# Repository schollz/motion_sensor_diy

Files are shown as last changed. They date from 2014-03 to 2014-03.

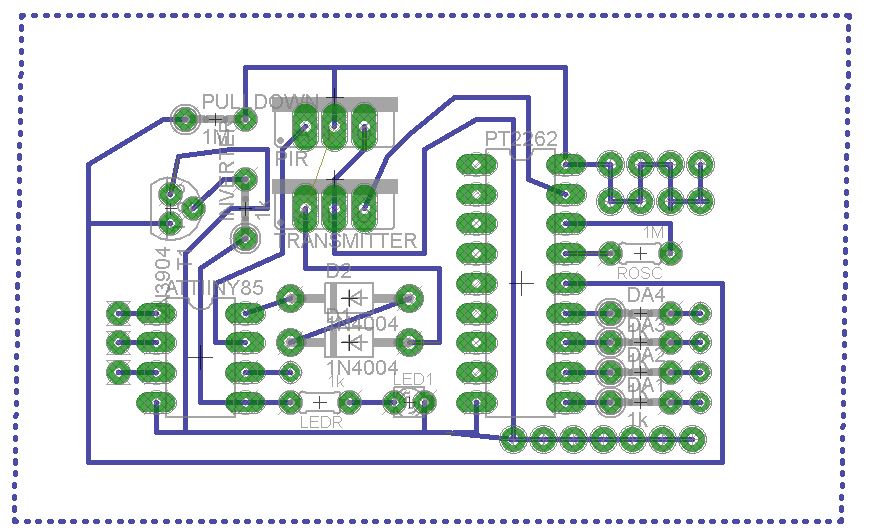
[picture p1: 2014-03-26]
eagle/rf_tx_board.JPG

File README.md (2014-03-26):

motion_sensor_diy
=================

Electronic schematics for RF motion sensor that uses Arduino as receiver hub

Instructions
=================

The eagle schematics show the wiring for the Motion Sensor and the Receiver. Each is very simple, here is the run down:

<h1>Motion sensor + RF transmitter</h1>

<strong>Components</strong>
<ul>
<li><a href="https://www.google.com/url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,d.cWc">PIR sensor</a>, on <a href="http://www.amazon.com/HC-SR501-Sensor-Module-Pyroelectric-Infrared/dp/B007XQRKD4">Amazon</a> or <a href="http://www.ebay.com/itm/10pcs-HC-SR501-Adjust-IR-Pyroelectric-Infrared-PIR-Motion-Sensor-Detector-Module-/131028677440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">Ebay</a></li>
<li><a href="http://www.100y.com.tw/pdf_file/PT2262-IRS.PDF">PT2262 encoder</a></li>
<li><a href="http://www.atmel.com/images/atmel-2586-avr-8-bit-microcontroller-attiny25-attiny45-attiny85_datasheet.pdf">ATtiny85</a></li>
<li><a href="http://www.amazon.com/433Mhz-transmitter-receiver-your-Experiment/dp/B00AMB3NCY">434 MHz RF transmitter</a></li>
<li>Several 500-1k Ohm resistors</li>
<li>LED (optional)</li>
</ul>

The motion sensor is simply a PIR sensor connected to a 434MHz RF transmitter via an encoder. The encoder uses four bits, in the form of resistors tied to HIGH (+VCC) or LOW (GND). That's enough for 12 sensors. 
The ATtiny85 is programmed via an Arduino which allows for devising a smart way of sending the RF data. It can be programmed to send the output as randomized timed sequences in order to reduce the conflicts of having other motion sensors on the same band.

<h1>RF Receiver</h1>

<strong>Components</strong>
<ul>
<li>Arduino</li>
<li>PT2272 encoder</li>
<li>434 MHz RF receiver</li>
</ul>

This circuit is even simpler. Connect the RF receiver output to the DIN of the PT2272. Then put each output pin (the four bits) into the Arduino pins 3-6. It's best to connect the VT (Viable Transmission indicator) pin of the PT2272 to the Pin 2 of the Arduino so that you can attach an interrupt on it. This way whenever VT goes high, the Arduino will read the other four pins and use that to determine which sensor is which (I leave this to you, though).

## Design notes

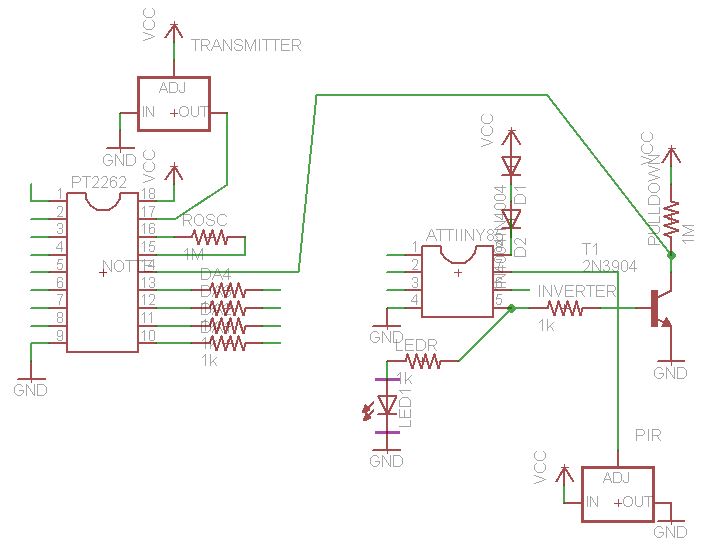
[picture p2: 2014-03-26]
eagle/rf_tx_schematic.JPG

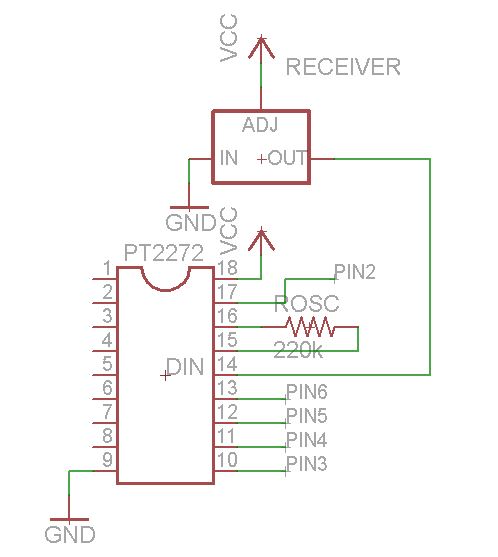
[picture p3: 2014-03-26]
eagle/rf_rx_schematic.JPG

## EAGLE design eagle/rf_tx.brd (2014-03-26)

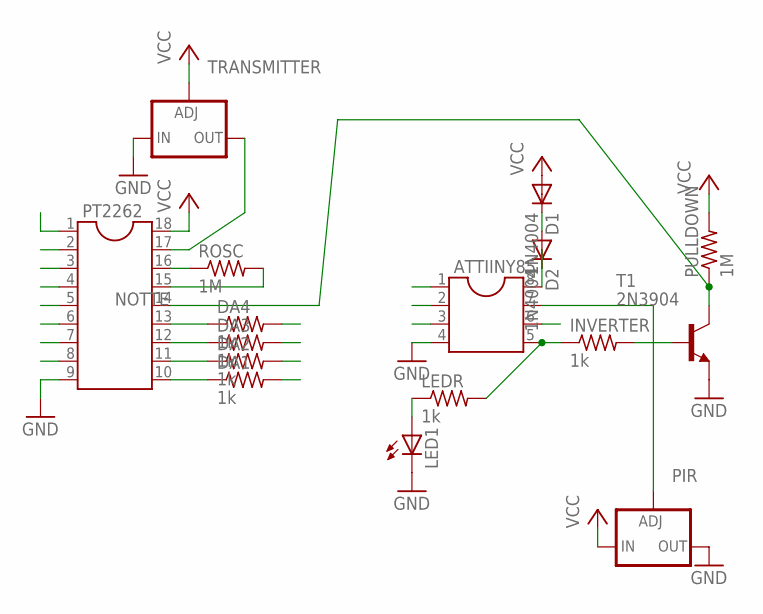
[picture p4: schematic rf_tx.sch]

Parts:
ATTIINY85: DIL8; DIL08
D1, D2: 1N4004; DO41-10
DA1, DA2, DA3, DA4: 1k; 0207/5V
INVERTER: 1k; 0207/5V
LED1: LED_ELD260; LED_LD260
LEDR: 1k; 0204/5
PIR: LM337TS; 337TS
PT2262: DIL18
PULLDOWN: 1M; 0207/5V
ROSC: 1M; 0204/5
T1: 2N3904; TO92
TRANSMITTER: LM337TS; 337TS

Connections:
GND: ATTIINY85.4, LED1.K (C), PIR.3 (OUT), PT2262.9, T1.3 (E), TRANSMITTER.2 (IN)
unnamed: D1.C, D2.A
unnamed: ATTIINY85.8, D2.C
unnamed: INVERTER.2, T1.2 (B)
unnamed: ATTIINY85.7, PIR.1 (ADJ)
unnamed: LED1.A, LEDR.1
unnamed: PT2262.17, TRANSMITTER.3 (OUT)
unnamed: PT2262.16, ROSC.1
unnamed: PT2262.15, ROSC.2
unnamed: DA1.1, PT2262.10
unnamed: DA3.1, PT2262.12
unnamed: DA2.1, PT2262.11
unnamed: DA4.1, PT2262.13
unnamed: ATTIINY85.5, INVERTER.1, LEDR.2
NOTTE: PT2262.14, PULLDOWN.1, T1.1 (C)
VCC: D1.A, PIR.2 (IN), PT2262.18, PULLDOWN.2, TRANSMITTER.1 (ADJ)

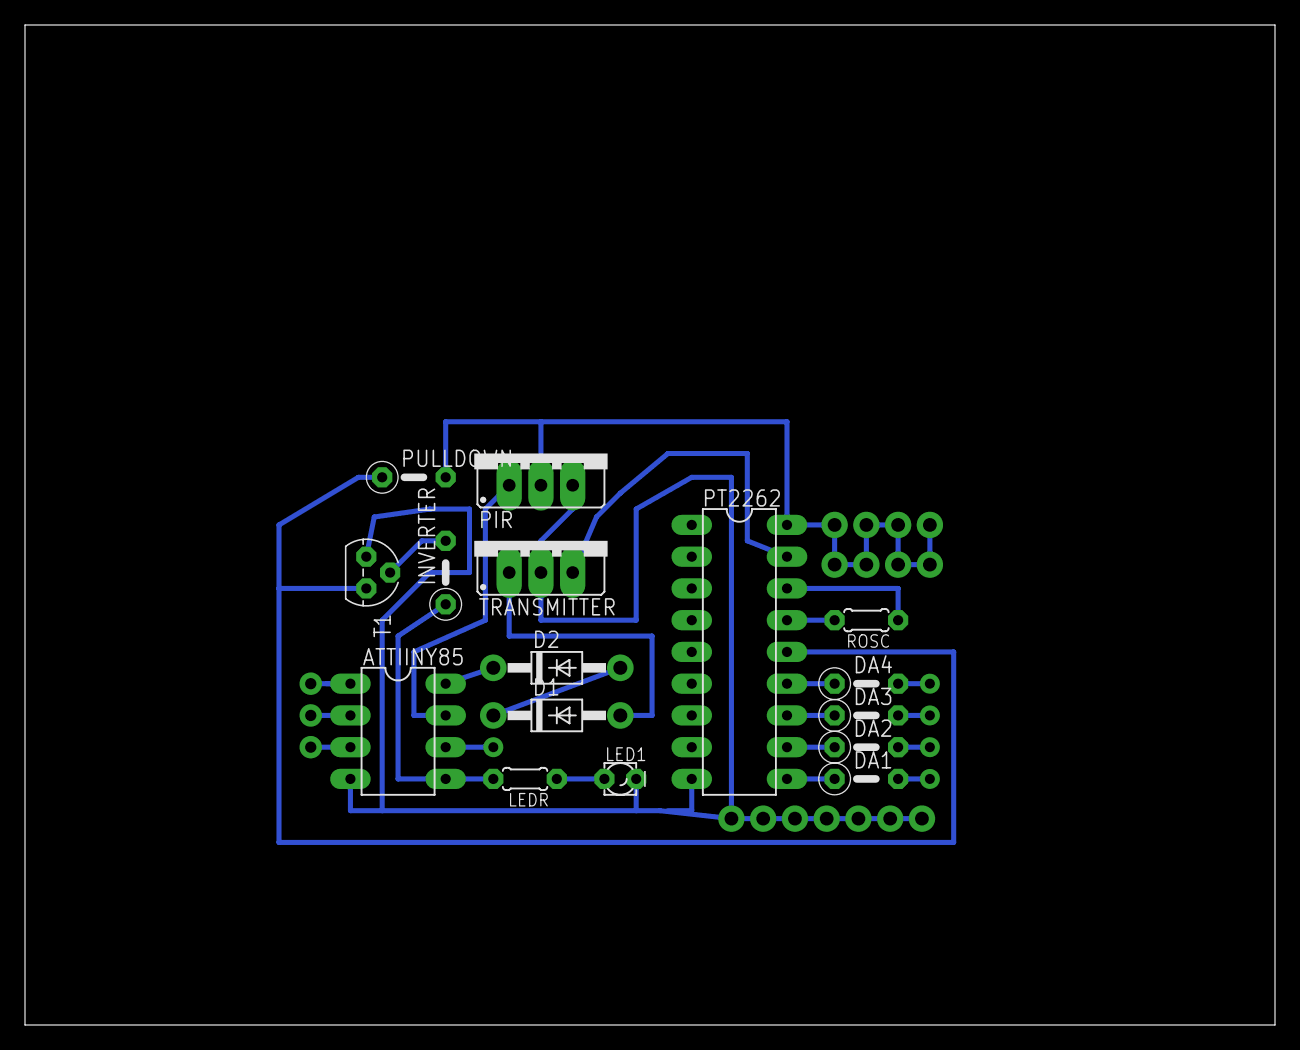
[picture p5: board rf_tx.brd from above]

Board: 2 copper layers, 100.0 x 80.0 mm, 16 parts (0 on the bottom side), 16 nets.

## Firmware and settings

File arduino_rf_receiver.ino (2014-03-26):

int ledpin = 13;
volatile int state = LOW;

void setup()
{
  pinMode(pin, OUTPUT);
  attachInterrupt(0, blink, CHANGE); //pin 2
  Serial.begin(9600);
}

void loop()
{
  digitalWrite(ledpin, state);
}

void blink()
{
  int a = digitalRead(3);
  int b = digitalRead(4);
  int c = digitalRead(5);
  int d = digitalRead(6);
  Serial.println(String(a) + " " + String(b) + " " + String(c) + " " + String(d) + " ");
  if (a+b+c+d>0){
    state = true;
  } else{
    state = false;
  }
}

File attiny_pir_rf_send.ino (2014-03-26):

#include <avr/sleep.h> //Needed for sleep_mode
#include <avr/wdt.h> //Needed to enable/disable watch dog timer

int pinLed = 0;
int irSensor = 2; // (pin 7 on chip)

void setup(){
  pinMode(pinLed,OUTPUT);
  pinMode(irSensor,INPUT);
    //Power down various bits of hardware to lower power usage  
  set_sleep_mode(SLEEP_MODE_PWR_DOWN); //Power down everything, wake up from WDT
  sleep_enable();
}

void loop(){
  ADCSRA &= ~(1<<ADEN); //Disable ADC, saves ~230uA
  setup_watchdog(5); //Setup watchdog to go off after 1sec
  sleep_mode(); //Go to sleep! Wake up 1sec later and check water

  //Check for water
  ADCSRA |= (1<<ADEN); //Enable ADC
    int val = digitalRead(irSensor);
    while (val == HIGH) {
        digitalWrite(pinLed, HIGH);   // turn the LED on (HIGH is the voltage level)
      delay(500);               // wait for a second
      val = digitalRead(irSensor);
    }
      digitalWrite(pinLed, LOW);    // turn the LED off by making the voltage LOW
}

//This runs each time the watch dog wakes us up from sleep
ISR(WDT_vect) {
  //Don't do anything. This is just here so that we wake up.
}

//Sets the watchdog timer to wake us up, but not reset
//0=16ms, 1=32ms, 2=64ms, 3=128ms, 4=250ms, 5=500ms
//6=1sec, 7=2sec, 8=4sec, 9=8sec
//From: http://interface.khm.de/index.php/lab/experiments/sleep_watchdog_battery/
void setup_watchdog(int timerPrescaler) {

  if (timerPrescaler > 9 ) timerPrescaler = 9; //Limit incoming amount to legal settings

  byte bb = timerPrescaler & 7; 
  if (timerPrescaler > 7) bb |= (1<<5); //Set the special 5th bit if necessary

  //This order of commands is important and cannot be combined
  MCUSR &= ~(1<<WDRF); //Clear the watch dog reset
  WDTCR |= (1<<WDCE) | (1<<WDE); //Set WD_change enable, set WD enable
  WDTCR = bb; //Set new watchdog timeout value
  WDTCR |= _BV(WDIE); //Set the interrupt enable, this will keep unit from resetting after each int
}

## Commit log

2014-03-26 added working boards
    [3_1_b_organized.brd, 3_1_b_organized.sch]
2014-03-26 Changed names
    [rf_tx.brd, rf_tx.sch]
2014-03-26 Images and updated rx board
    [rf_rx.sch]
2014-03-26 arduino and attiny code updated
